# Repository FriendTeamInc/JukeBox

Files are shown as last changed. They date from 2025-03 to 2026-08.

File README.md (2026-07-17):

<p align="center">JukeBox!</p>
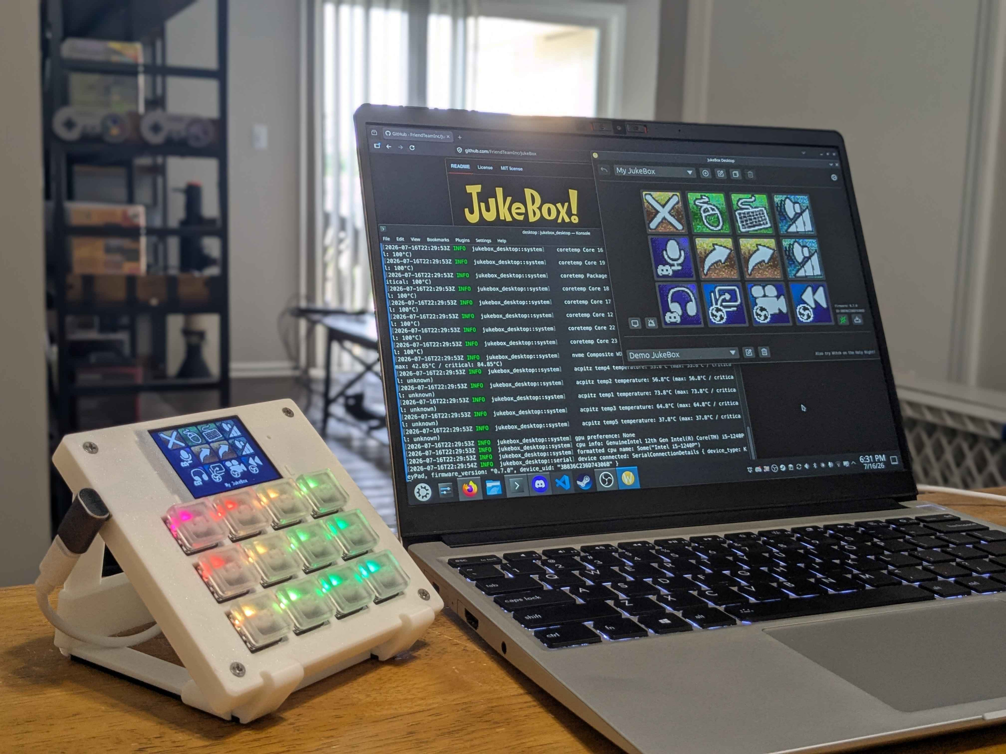
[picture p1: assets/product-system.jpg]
A JukeBox unit sitting idle on a desk with a computer.

<p align="center">An affordable, adorable, powerful hotkey device to run macros, play funny sounds, managing your audio settings, change paint brush settings, configure items in OBS, and so much more!</p>

# Disclaimer
While this project is public, it is not ready for any sort of prime time. Any releases prior to 1.0 are considered beta.

## Docs
TODO

## Desktop Software
Made with Rust and egui for Windows and Linux, curates the user experience with the JukeBox.

### Building
It's as simple as running `cargo build --release`.

### Discord support
Discord, currently, will not provide support to new projects using their RPC protocol. Because of this, JukeBox Desktop will not support Discord out of the box, despite having functionality for it built in. To use the Discord functionality in JukeBox Desktop, you must do the following:
1. Go to https://discord.com/developers/applications/ and log in with your account.
2. Create a new application and name it JukeBoxDesktop.
3. Go to the OAuth2 settings tab.
4. Copy the client ID and client secret down to a safe location.
5. Set the redirect to `https://localhost:61961`. Save your changes.
6. Go to the App Testers settings tab.
7. Add your Discord account as a tester. An email will be sent to your account email, go to your inbox and accept the invite.
8. Build with the following command: `DISCORD_CLIENT_ID="<PUT_CLIENT_ID_HERE>" DISCORD_CLIENT_SECRET="<PUT_CLIENT_SECRET_HERE>" cargo run --features "discord" --release`.

## Device Firmware
TODO

### Building
1. (Linux only) Add yourself to the dialout group with the following: `sudo usermod -a -G dialout $USER`. Install the [RPi Pico udev rules](https://github.com/raspberrypi/picotool/blob/master/udev/99-picotool.rules). Add the following rules:
```
SUBSYSTEM=="usb", \
    ATTRS{idVendor}=="2e8a", \
    ATTRS{idProduct}=="000c", \
    TAG+="uaccess" \
    MODE="660", \  
    GROUP="plugdev"
```

2. Install the appropriate target toolchain: `rustup target add thumbv6m-none-eabi`.
3. Install [cmake](https://cmake.org/download/) for tool compilation.
4. (Linux only) Install libudev-dev: `sudo apt install libudev-dev`.
5. Install tools: `cargo install flip-link`.
5. Install tools: `cargo install --locked probe-rs-tools`. This is for installing firmware over Pico probe.
6. Run `cargo run -F "keypad"` to install the keypad firmware to the connected device. You can use pedalpad or knobpad too.

## Case
Made with OpenSCAD 2025.03.31 (development snapshot), protects everything inside the JukeBox. You can get the printable STLs with the `build.sh` script.

## PCB
Made with KiCad 10, the external brains of the JukeBox.

Footprints and models:
- [Cherry/Kailh Switch footprint based on this.](https://github.com/luke-schutt/Pi5Keyboard/blob/main/Pi5-pcb/Pi5Footprints.pretty/Low%20Profile%20GC%20plus%20MX.kicad_mod)

Estimated power usage is 5 volts at 0.1 amps, or 0.5 watts.

### Bill of Materials
| Ref | Part No. | Qty | Value | DNP |
|---|---|-----|---|-----|
| R1, R5, R14 | RMCF0402FT1K00 | 3 | 1k | |
| R3, R4 | RMCF0402FT27R0 | 2 | 27 | |
| R6, R7 | RMCF0402FT5K11 | 2 | 5.11k | |
| R8-11 | RMCF0402FT10K0 | 4 | 10k | |
| R12 | RMCF0402FT10K0 | 1 | 10k | |
| R13 | RMCF0402FT10R0 | 1 | 10 | |
| R15 | RMCF0402FT33R0 | 1 | 33 | |
| C1, C2 | GRM21BR61C106KE15K | 2 | 10u | |
| C3, C4 | GCM1555C1H150JA16D | 2 | 15p | |
| C5, C9, C11-18 | GRM155R71E104KE14J | 10  | 100n  | |
| C6-8, C10 | GRM155R60J475ME47D | 4 | 4.7u  | |
| L1 | AOTA-B201610S3R3-101-T | 1 | 3.3u  | |
| D1-12 | 1N4148W-SOD-123 | 12  | | |
| D13-24 | WS2812B-2020 | 12  | | |
| D25 | 150080GS75000 | 1 | | |
| J1 | USB4105-GF-A | 1 | | |
| Q1 | S8050-SOT-23 | 1 | | |
| SW1-12 | Keyboard Key Switch | 12  | |  X  |
| SW13 | PTS636SKG25SMTR LFS | 1 | | |
| U1 | AZ1117IH-3.3TRG1 | 1 | | |
| U2 | W25Q32JVSSIQ | 1 | | |
| U3 | RP2350A | 1 | | |
| U4 | TFTQ-T20ST22ZP01 | 1 | |  X  |
| U4 | FH34SRJ-22S-0.5SH(50)  | 1 | | |
| U5 | CAT24C128WI-GT3 | 1 | | |
| Y1 | ABM8-272-T3 | 1 | | |

# License
Copyright (c) 2020-2026 Logan "NotQuiteApex" Hickok-Dickson

All programming files, found in [`firmware/`](firmware/), [`software/`](software/), and [`case/`](case/), are licensed under the [MIT license](https://mit-license.org/).

All CAD files, found in [`hardware-pcb/`](hardware-pcb/), unless otherwise provided by an external source such as footprints or 3D models, are licesned under the [CC BY-NC-SA license](https://creativecommons.org/licenses/by-nc-sa/4.0/).

Both licenses can be found with the given links or as files in the root of this repostiory.

If you would like to sell a variation of the board designed by you, reach out and an alternative license can be discussed and granted.

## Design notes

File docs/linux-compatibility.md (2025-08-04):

# Linux Compatibility
You must add yourself to the `dialout` group in order for device communication to function: `sudo usermod -a -G dialout $USER`

You must also install the udev rules below for device communication to function.

## udev Rules
The following udev rules allow device communication access for all users in the dialout group, and device firmware update permissions for all users in the plugdev group. The latter is only necessary for manual updating.
```udev
SUBSYSTEM=="tty", ATTRS{idVendor}=="1209", ATTRS{idProduct}=="f209", TAG+="uaccess" MODE="0660", GROUP="dialout"
SUBSYSTEM=="tty", ATTRS{idVendor}=="1209", ATTRS{idProduct}=="f20a", TAG+="uaccess" MODE="0660", GROUP="dialout"
SUBSYSTEM=="tty", ATTRS{idVendor}=="1209", ATTRS{idProduct}=="f20b", TAG+="uaccess" MODE="0660", GROUP="dialout"
SUBSYSTEM=="tty", ATTRS{idVendor}=="1209", ATTRS{idProduct}=="f20c", TAG+="uaccess" MODE="0660", GROUP="dialout"
SUBSYSTEM=="usb", ATTRS{idVendor}=="2e8a", ATTRS{idProduct}=="0003", TAG+="uaccess" MODE="0660", GROUP="plugdev"
```

## Dependencies
Debian/Ubuntu:
`sudo apt install libgtk-3-dev libxdo-dev libayatana-appindicator3-dev`

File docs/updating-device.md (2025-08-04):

# Updating Your JukeBox Device Firmware
There are two methods for updating your JukeBox, using the desktop application and manually flashing the firmware.

## 1. Updating via the Desktop Application
1. Connect your device to your computer and open the desktop application. Your device is connected when the desktop application shows a green plug symbol.
2. Click the update button next to the green plug symbol to open the update page. Do note, that if you haven't already, you may need to configure the device to be allowed to update on [Windows with Zadig](windows-compatibility.md#updating-the-device-firmware) or [Linux with udev rules](windows-compatibility.md#updating-the-device-firmware).
3. Click the front and center update button, and allow the application to flash new firmware onto the device. You can also load a custom firmware file with the CFW button, though this is not recommended nor supported.
4. All done! Enjoy your updated device!

## 2. Manually Flashing New Firmware on Tour Device
1. Unplug the device from your computer.
2. Locate the BOOT button on your device. Hold this button down.
    - On the JukeBox KeyPad, this BOOT button is above the rightmost key next to the screen.
3. While holding the button, connect the device to your computer. The device SHOULD NOT boot or light up normally.
4. Let go of the BOOT button. A USB storage device should appear in your file explorer, named something like "RPI-RP2".
5. Download the latest firmware [here](https://github.com/FriendTeamInc/JukeBox/releases/latest). The firmware is a UF2 file.
6. Drag and drop the firmware into the "RPI-RP2" storage device and wait for the transfer to complete. When finished, your JukeBox device will reboot with the latest firmware installed.
7. All done! Enjoy your updated device!

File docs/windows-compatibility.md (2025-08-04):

# Windows Compatibility
Windows users should not need any extra software or drivers to use the JukeBox device or desktop application. However, updating the firmware using the desktop application does require the installation of a Zadig driver.

## Updating the Device Firmware
If you have not done so before, when updating the device firmware you will need to install a driver for the device to be updated by the desktop application. To do so, follow these steps:

1. Connect your device to your computer, open the application, and open the firmware update page for your device when the device connects.
2. Click the update button. The device will reboot with a blank screen, and the update will fail with an error. Do NOT unplug the device yet.
3. Download and open [Zadig](https://zadig.akeo.ie/). In the dropdown, find and select the device named "RP2 Boot". For the driver, select WinUSB and click the install button. You are free to close Zadig now.
4. Now, reconnect your device to your computer, it should appear to function as it did before.
5. Navigate back to the firmware update page for your device, and attempt to update the device. It should reboot successfully with the latest firmware installed.

From now on you should be free to install new firmware using just the desktop application!

## Problematic Software
The following programs are known to cause issue with serial ports, which JukeBox uses to communicate between the device and the application over USB. When these applications run, it may be impossible for the JukeBox device to connect to the desktop application.

- [UltiMaker Cura](https://ultimaker.com/software/ultimaker-cura/)
- [NZXT CAM](https://nzxt.com/pages/cam)

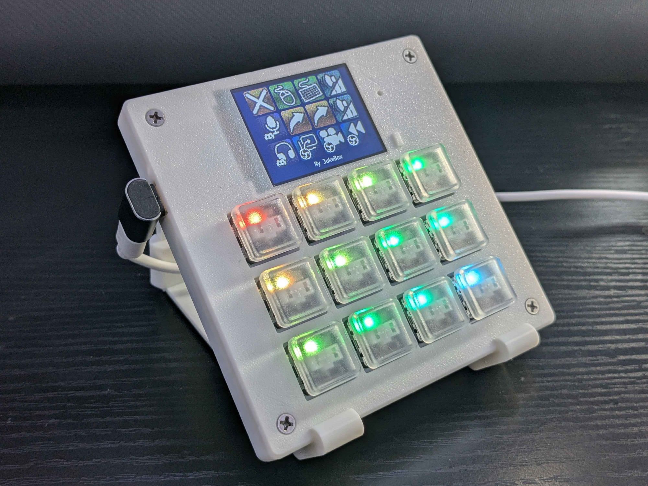
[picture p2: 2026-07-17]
assets/product-solo.jpg

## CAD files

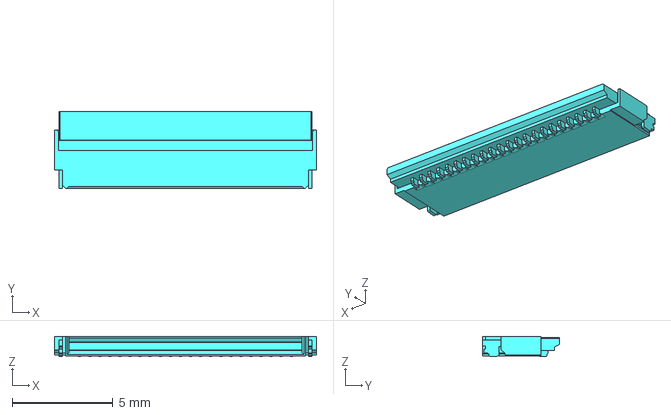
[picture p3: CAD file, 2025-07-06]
pcb/footprints/FH34SRJ-22S-0.5SH_50_.step
13.0 x 3.80 x 1.00 mm

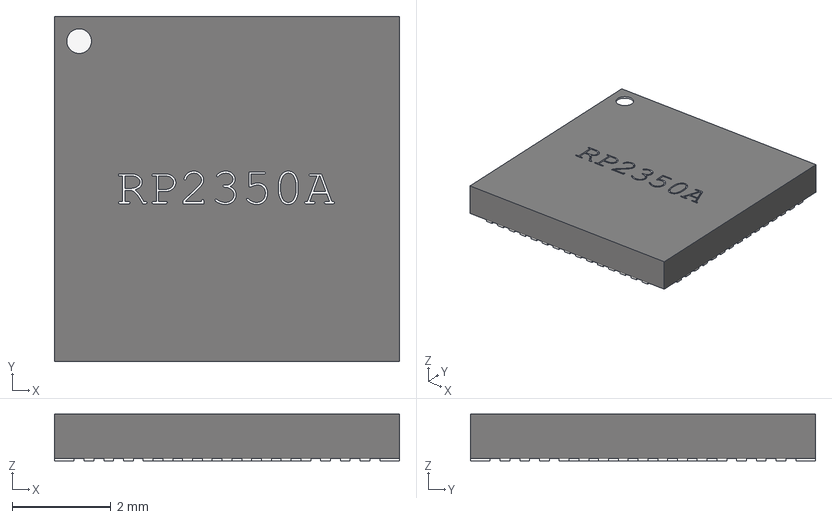
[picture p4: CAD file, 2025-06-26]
pcb/footprints/RP2350_QFN60.step
7.00 x 7.00 x 0.95 mm

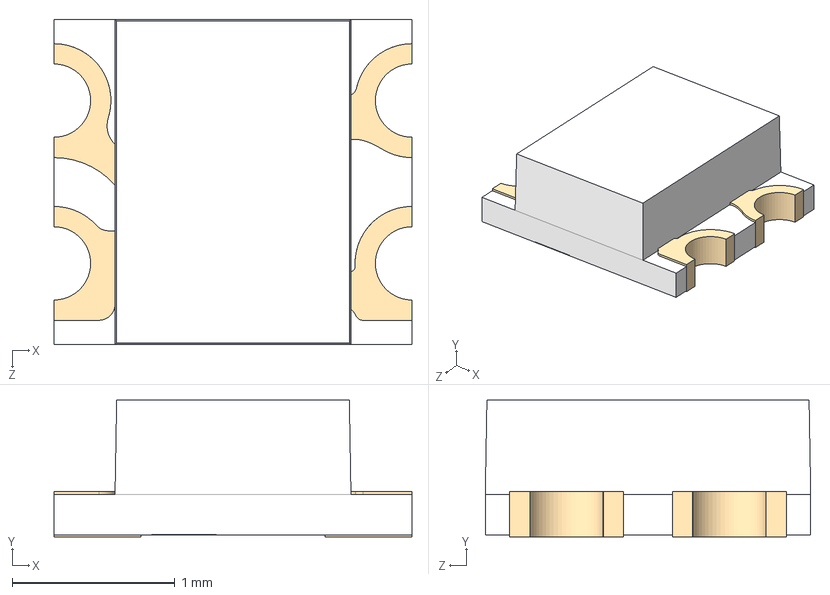
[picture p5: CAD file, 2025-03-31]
pcb/footprints/WS2812-2020.STEP
2.20 x 0.84 x 2.00 mm

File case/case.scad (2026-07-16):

// JukeBox Case

/* [General settings] */
// Case size (width & height)
cS = 108;
// Case corner radius (rounded corners)
cR = 3;
// Case mounting hardware offset
cmO = 7.5;
// Case mounting hardware bolt size
cmB = 3.5;
// Case mounting hardware nut size (center to corner)
cmN = 3.3;
// Face count on rounded objects
$fn=32;
// Case connector hole size
ioHS = 10;
// Case connector hole offset
ioHO = cS-cmO-17.5;
// Case connector hole buffer
ioHB = 0.125;
// Debug Port
dbgPort = false;
// Reset button width
rbW = 2.5;
// Reset button height
rbH = 5;

/* [Case top settings] */
// Case top height
ctH = 8;
// Case top wall size
ctW = 2.5;
// Case top mounting plate size
ctM = 9;
// Case top mounting plate height
ctMH = 3.4;

/* [Case bottom settings] */
// Case bottom lip height
clH = 3;
// Case bottom lip chamfer size
clC = 1;
// Case bottom lip size
clS = 3;
// Case bottom PCB corner radius (rounded corners)
cpR = 3;
// Case bottom PCB height
cpH = 2.6;
// Case bottom PCB wall size
cpW = 3;
// Case bottom PCB mounting plate size
cpM = 9;
// Case bottom rubber feet spot offset
cpF = 20;
// Case bottom rubber feet spot diameter
cpFD = 10;
// Case bottom rubber feet spot depth
cpFH = 2;

/* [Logo settings] */
// Logo size scale
logoS = 0.035;
// Logo position (X)
logoX = 49;
// Logo position (Y)
logoY = 83;

/* [Keyboard settings] */
// Keyboard key size
kbS = 17;
// Keyboard key matrix position (X)
kbX = cS/2;
// Keyboard key matrix position (Y)
kbY = 39;
// Keyboard key matrix offset (X)
kbOX = 30;
// Keyboard key matrix offset (Y)
kbOY = 20;
// Keyboard key matrix width
kbW = 4;
// Keyboard key matrix height
kbH = 3;
// Keyboard key matrix spacing width
kbSW = 20;
// Keyboard key matrix spacing height
kbSH = 20;

/* [Case leg settings] */
// Leg width
clipW = 13;
// Leg rounding radius
clipR = 4;
// Leg Brace width
braceW = 20;

/* [Case screen settings] */
// Screen Cutout width
csScrCW = 57.5;
// Screen Cutout height
csScrCH = 36.5;
// Screen Window width
csScrWW = 42.5;
// Screen Window height
csScrWH = 32.5;

module rect4(x1, y1, x2, y2, h) {
    translate([x1, y1, h]) children();
    translate([x2, y1, h]) children();
    translate([x1, y2, h]) children();
    translate([x2, y2, h]) children();
}
module square4(s1, s2, h) {
    rect4(s1, s1, s2, s2, h) children();
}
// https://www.youtube.com/watch?v=gKOkJWiTgAY
module roundedsquare(xdim, ydim, zdim, rdim){
    hull() {
        rect4(rdim, rdim, xdim-rdim, ydim-rdim, 0) cylinder(h=zdim, r=rdim);
    }
}
module chamferedsquare(xdim, ydim, zdim, r1dim, r2dim){
    bigrdim = max(r1dim, r2dim);
    hull() {
        rect4(bigrdim, bigrdim, xdim-bigrdim, ydim-bigrdim, 0) cylinder(h=zdim, r1=r1dim, r2=r2dim);
    }
}

module speaker_icon() {
    scale([5/6, 5/6, 1]) {
        difference() {
            cylinder(r=7, h=1, center=true);
            cylinder(r=6, h=1, center=true);
        }
        cube([1, 13, 1], center=true);
        translate([ 4, 0, 0]) cube([1, 10, 1], center=true);
        translate([-4, 0, 0]) cube([1, 10, 1], center=true);
        translate([0, -2.25, 0]) cube([12, 1, 1], center=true);
        translate([0,  2.25, 0]) cube([12, 1, 1], center=true);
    }
}

SOX = cS / 2 - (csScrCW + ctW * 2) / 2; // screen origin x
SOY = cS - 18 - ctW - csScrCH / 2-2.75; // screen origin y

module case_reset_button() {
    b = 3;
    c = 0.25;
    cube([rbW+b, rbH+b, 0.4]);
    translate([b/2+c/2, b/2+c/2, 0.4]) cube([rbW-c, rbH-c, 2.4]);
}

module case_top() {
    difference() {
        union() {
            difference() {
                union() {
                    // Top shell body
                    translate([0, 0, ctH]) chamferedsquare(cS, cS, 1, 3, 2);
                    roundedsquare(cS, cS, ctH, cR);
                }
                union() {
                    // USB-C hole
                    translate([-1, ioHO-ioHS, -1]) cube([ctW+2, ioHS, ctH+1]);
                    // Interior
                    translate([ctW, ctW, -1]) roundedsquare(cS-ctW*2, cS-ctW*2, ctH+1, cR);

                    // identify led cutout
                    translate([cS-25.5, cS-17.5, ctH]) cylinder(h=1, d=2);
                    // reset button cutout
                    translate([cS-28.75, cS-36.75, ctH]) cube([rbW, rbH, 1]);
                }
            }

            // LED light pipe
            difference() {
                translate([cS-25.5, cS-17.5, ctH-2.8]) cylinder(h=2.8, d=4);
                translate([cS-25.5, cS-17.5, ctH-2.8]) cylinder(h=2.8, d=2);
            }

            h = ctH-ctMH;
            ctMW = ctM+ctW;

            // Mounting plates
            square4(0, cS-ctMW, h) roundedsquare(ctMW, ctMW, ctMH, cpR);
            translate([    cmO,           0, h]) cube([cS - cmO*2, ctM+1.5, ctMH]);
            translate([    cmO,    cS-cmO-4, h]) cube([cS - cmO*2, ctM+1.5, ctMH]);
            translate([      0,           0, h]) roundedsquare(ctMW, ctMW+60, ctMH, cpR);
            translate([cS-ctMW,           0, h]) roundedsquare(ctMW, ctMW+60, ctMH, cpR);
            translate([      0,  cS-ctMW-12, h]) roundedsquare(ctMW, ctMW+12, ctMH, cpR);

            // Supports (screen)
            translate([SOX, SOY, 0]) union() {
                translate([ctW+(csScrCW+csScrWW)/2+2, ctW+(csScrCH+csScrWH)/2-.75, h]) cube([20, 3, ctMH]);
                translate([ctW-(csScrCW-csScrWW)/2-12.5, ctW+(csScrCH+csScrWH)/2-.75, h]) cube([20, 3, ctMH]);

                translate([ctW+(csScrCW-cS)/2, 1, h]) cube([cS, 1.5, ctMH]);
            }

            // Supports (keyboard)
            translate([0, 47.5, h]) cube([cS, 3, ctMH]);
            translate([0, 27.5, h]) cube([cS, 3, ctMH]);

            // alignment holders
            difference(){
                bS = 100;
                bBS = 0.25;
                translate([0, 0, h-1]) roundedsquare(cS, cS, 1, cR);
                translate([(cS-(bS+bBS))/2, (cS-(bS+bBS))/2, h-2]) cube([bS+bBS, bS+bBS, 2]);
                translate([0, cS-36.5, h-2]) cube([cS, 25, 2]);
            }
        }

        union() {
            // keyboard key holes
            kX = kbX-kbOX;
            kY = kbY-kbOY;
            ch = ctH + 1;
            for (w=[0:kbW-1]) {
                for (h=[0:kbH-1]) {
                    translate([kX + kbSW * w, kY + kbSH * h, ch]) cube([kbS, kbS, 2], center=true);
                }
            }

            // mounting hardware holes
            square4(cmO, cS - cmO, ctH - 4) {
                cylinder(d=cmB, h=5);
                translate([0, 0, 2]) cylinder(d2=6, d1=2, h=3);
            }


            // Screen cutout
            translate([SOX, SOY, 0]) union() {
                // Screen Window
                translate([ctW+(csScrCW-csScrWW)/2, ctW+(csScrCH-csScrWH)/2, ctH]) cube([csScrWW, csScrWH, 1]);
                // Inset
                translate([ctW+(csScrCW+csScrWW)/2+2-52, 2.5, 0]) cube([52, csScrCH, 8.8]);
            }
            
            // Jukebox logo
            // case_detail();

            // Debug port cutout
            if (dbgPort) {
                translate([cS-ctW, cS-17.5-4-18, 0]) cube([ctW, 18, ctH-ctMH]);
            }
        }
    }
}

module case_bottom() {
    difference() {
        union() {
            // Case floor
            chamferedsquare(cS, cS, clC, cR-clC, cR);
            translate([0, 0, clC]) roundedsquare(cS, cS, clH-clC, cR);

            // PCB table
            difference() {
                translate([    clS,     clS, clH]) roundedsquare(cS-clS*2, cS-clS*2, cpH, cpR);
                translate([clS+cpW, clS+cpW, clH]) cube([cS-clS*2-cpW*2, cS-clS*2-cpW*2, cpH]);
            }
            square4(clS, cS-clS*2-cpW*2, clH) roundedsquare(cpM, cpM, cpH, cpR);

            // USB-C pillar
            translate([0, ioHO-ioHS+ioHB, clH]) cube([1.5, ioHS-ioHB*2, 4]);
        }

        union() {
            cmO2 = cS-cmO;
            nH = 2.375;
            square4(cmO, cmO2, 0) cylinder(d=cmB, h=7);
            square4(cmO, cmO2, 0) cylinder($fn=6, r=cmN, h=nH);
            square4(cmO, cmO2, nH) cylinder($fn=6, r1=cmN, r2=cmB/2, h=1);

            // Indents for rubber feet
            square4(cpF, cS-cpF, 0) cylinder(d=cpFD, h=cpFH/2);
            square4(cpF, cS-cpF, cpFH/2) cylinder(d1=cpFD, d2=cpFD-2, h=cpFH/2);

            // cutout for through hole components
            translate([clS, ioHO-ioHS+ioHB, clH]) cube([10, ioHS-ioHB*2, cpH]);

            // Debug port cutout
            if (dbgPort) {
                translate([cS-ctW-20, cS-17.5-4-18, clH]) cube([ctW+20, 18, ctH]);
            }
        }
    }
}
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

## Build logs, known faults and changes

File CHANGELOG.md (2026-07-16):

# v0.7.0 - Asynchronous (July 15, 2026)
Note: This update is for a new hardware revision of JukeBox and will not work with older beta units. Do not use this or newer versions with older hardware.
- Upgrade microcontroller to RP2350 (from RP2040).
- Switch firmware to use Embassy for better task management on device.
- Upgrade screen (same ST7789 interface, larger bus size from 1 bit to 8 bits).
- Upgrade case to support new hardware.
- Fix screen and RGB editor in desktop app.
- Fix temperature reporting for certain CPUs.
- Improve connection to OBS and Discord on startup.
- Dramatically improve screen graphics performance.
- Dynamically dim and brighten screen on computer sleep and wakeup.
- Add dynamic icons for certain actions to display status, such as being muted on Discord.
- Add profile duplicate button.
- Profiles now switch when creating a new profile or duplicating a profile.
- Re-enable system tray support for Windows.
- Update dependencies for desktop app and firmware.

# v0.6.1 - But Not Serialized (August 5, 2025)
- Fix firmware having too big of a serial buffer, causing a crash on startup.
- Fix versioning issue with firmware and software.
- Fix action icon size in software.

# v0.6.0 - Defaultized (August 5, 2025)
- Added EEPROM support to firmware. A default, app-disconnected profile can now be set. Support in GUI will be added at a later date.
- Added "sleep mode" for when host computer goes to sleep (suspends USB), turning off the screen and RGB.
- Increase max number of colors for Wave and Breathe RGB patterns from 4 to 16.
- Update Screen profile max size to be 256 bytes.
- Update RGB Profile max size to be 64 bytes.
- Unify USB HID Events (keyboard and mouse) in code and protocol.
- Update links to documentation for Windows and Linux setup intro messages.
- Add a drop down select for RGB Static Per Key pattern.
- Change default profile in software for keypad to the F13-24 keys.
- Fix identify function having messed up offsets for the blinking LED.
- Allow profile name to be hidden on screen.
- Update dependencies for desktop app and firmware.

# v0.5.0 - Tut Trials (June 27, 2025)
- Add a welcome message on very first startup with some important info for the user.
- Remove donate "link".
- Add "Breathe" RGB pattern configuration.
- Add "Wave" RGB pattern configuration.
- Fix RGB previews, specifically the rounded corners.
- Enable NVIDIA GPU monitoring support. AMD support will be added later once cross compiling is sorted.
- Update dependencies for desktop app and firmware.

# v0.4.6 - I'm Blue (June 26, 2025)
- Update default theme for device when not connected to application. This now includes an indicator of USB connection status (red if not connecting, green if connected with host), the device's UID, and its firmware version. It's also blue now.
- Fix "N/A" temperature not displaying correctly on device.

# v0.4.5 - Clock Forever (June 22, 2025)
- Fix keyboard key requests being way too frequent.
- Only send RGB and Screen packets to keypad devices, futureproofing.

# v0.4.4 - Initiliazing Fixes (June 22, 2025)
- Fix potential device nickname collisions on first connection.
- Fix device not receiving default configuration on first connection.

# v0.4.3 - Patch TODOs (June 21, 2025)
- Switch Profile action will now better switch its target profile when the original target profile is deleted or renamed.
- Disable CPU temperature read out on Windows (since Windows and sysinfo do not have methods to read temperature currently).
- Add info statement to list device firmware and UID on connection.
- Fix application remembering device firmware of a disconnected device.
- Take last 4 characters of UID for name instead of first 4 due to collisions.
- Fix panics and stuck loops when packet length read fails.
- Fix stuck loop when serial disconnects with data in its buffer.
- The above fixes do not solve the random disconnects that serial experiences, and will need to be investigated further later. For some reason, either the application drops random bytes, or the firmware consumes random bytes.

# v0.4.2 - IADs Fix (June 15, 2025)
- Fix device not functioning on Windows due to misconfigured USB descriptors.

# v0.4.1 - Feelin' Hot (June 14, 2025)
- Add preliminary CPU temperature reading support. This may only work on AMD-based CPU's, and has been only tested on Linux.

# v0.4.0 - Mouse Controls, Not for Mice (June 14, 2025)
- Add mouse event action in app and firmware.
- Fix device not appearing correctly as composite device.
- Fix device not requesting enough power.
- Fix device max packet size to be larger for performance.
- Update some firmware dependencies.

# v0.3.1 - Update Fixes (June 13, 2025)
- Fix inability to leave other screens after a failed update occurred.

# v0.3.0 - Icon and Save Update (June 13, 2025)
- Images of arbitrary size can be used as icons now.
- Device connection status is now more prominent.
- Added popup warning for if your config file failed to load.
- Added explicit save button on configuration screens.
- Further increase timeout of serial to be at most 250 milliseconds.

# v0.2.5 - More Stability (June 12, 2025)
- Fix USB mass storage device from appearing when the JukeBox is put into update mode from software.
- Fix firmware update confirmation button translation string.
- Adjust USB serial internal buffer sizes in firmware.
- Revert tray icon functionality for Windows while we wait for egui to add `App::tick()`.
- Force timeout of serial to be at most 100 milliseconds.
- Update firmware dependencies.

# v0.2.4 - Firmware Update Stability (June 11, 2025)
- Update internal libraries. This specifically addresses an issue where the firmware update page may fail when no drivers are available on Windows.
- Added a message to the firmware update error page to reconnect the device physically or manually update the firmware.

# v0.2.3 - Iconic Async (June 11, 2025)
- Fix icon device upload in async thread.

# v0.2.2 - Debugging Causes Problems (June 9, 2025)
- Add pop up for any errors from the update process.
- Allow console window on Windows, for any panics to be traced. This will be removed later.
- Disable blocking in firmware debug output, which causes firmware to eventually freeze.

# v0.2.1 - Albrecht Entrati (June 8, 2025)
- Major refactor internally for actions. Old config files will be discarded!
- Add lots of debug prints for the update process.
- Fix config directory missing for app lock purposes.
- Begin push for Discord integration available by default. Unfinished.
- Changed delete profile and forget device to be single click instead of double click.
- The save and exit pop up will now only show when a change has actually been made.
- Drop some old dependencies from the desktop app.

# v0.2.0 - Debugging Days (June 8, 2025)
- Changed default brightness for RGB from 255 to 100.
- Added log file for testers to send in.
- Prevent new instances of the desktop application from launching.

# v0.1.3 - Removing Some Unfinished Work (June 3, 2025)
- Fix crash when GPU name is too long.
- Rename Profile Name Color to Text Color in screen configuration.
- Finish brightness in screen configuration.
- Disabled Soundboard functionality, since it is currently unfinished.
- Disabled Wave RGB pattern, since it is currently unfinished.
- Vertically expanded the window, since on certain platforms the window is cut off at the bottom.

# v0.1.2 - Allow Updating Firmware (June 1, 2025)
- Desktop application can now download and apply new firmware.

# v0.1.1 - Minor Update Notif Fix (June 1, 2025)
- Change the Update Notification in the desktop application to show the current and new version.
- Update desktop app dependencies.
- Add changelog.

# v0.1.0 - Beta Begins (June 1, 2025)
Initial release.

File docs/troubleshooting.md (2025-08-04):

# General Troubleshooting
When you first plug in your JukeBox device, before it connects to the desktop application, it will show you several important elements.

First, a box on the bottom left to indicate USB connectivity. This box will be red if the device cannot exchange information with the host computer, which can happen if your USB cable or port malfunctions. Try using another port, another orientation, or another cable. The box will be green if the device and host computer are communicating.

Second, a unique identifier (UID) will appear at the bottom middle of the screen. This string of letters and numbers uniquely identifies this JukeBox, and is determined by the flash storage chip used on the device. This UID will also appear in your desktop application.

Third, a firmware version number in the bottom right. It's good practice to always make sure your device is up-to-date. If your device can connect to the desktop application, you can [update your device using the desktop application](flashing-firmware.md#1-updating-via-the-desktop-application). If for whatever reason the device can be detected by the host computer, but not the desktop application, you may need to [manually flash the firmware](flashing-firmware.md#2-manually-flashing-new-firmware-on-tour-device).

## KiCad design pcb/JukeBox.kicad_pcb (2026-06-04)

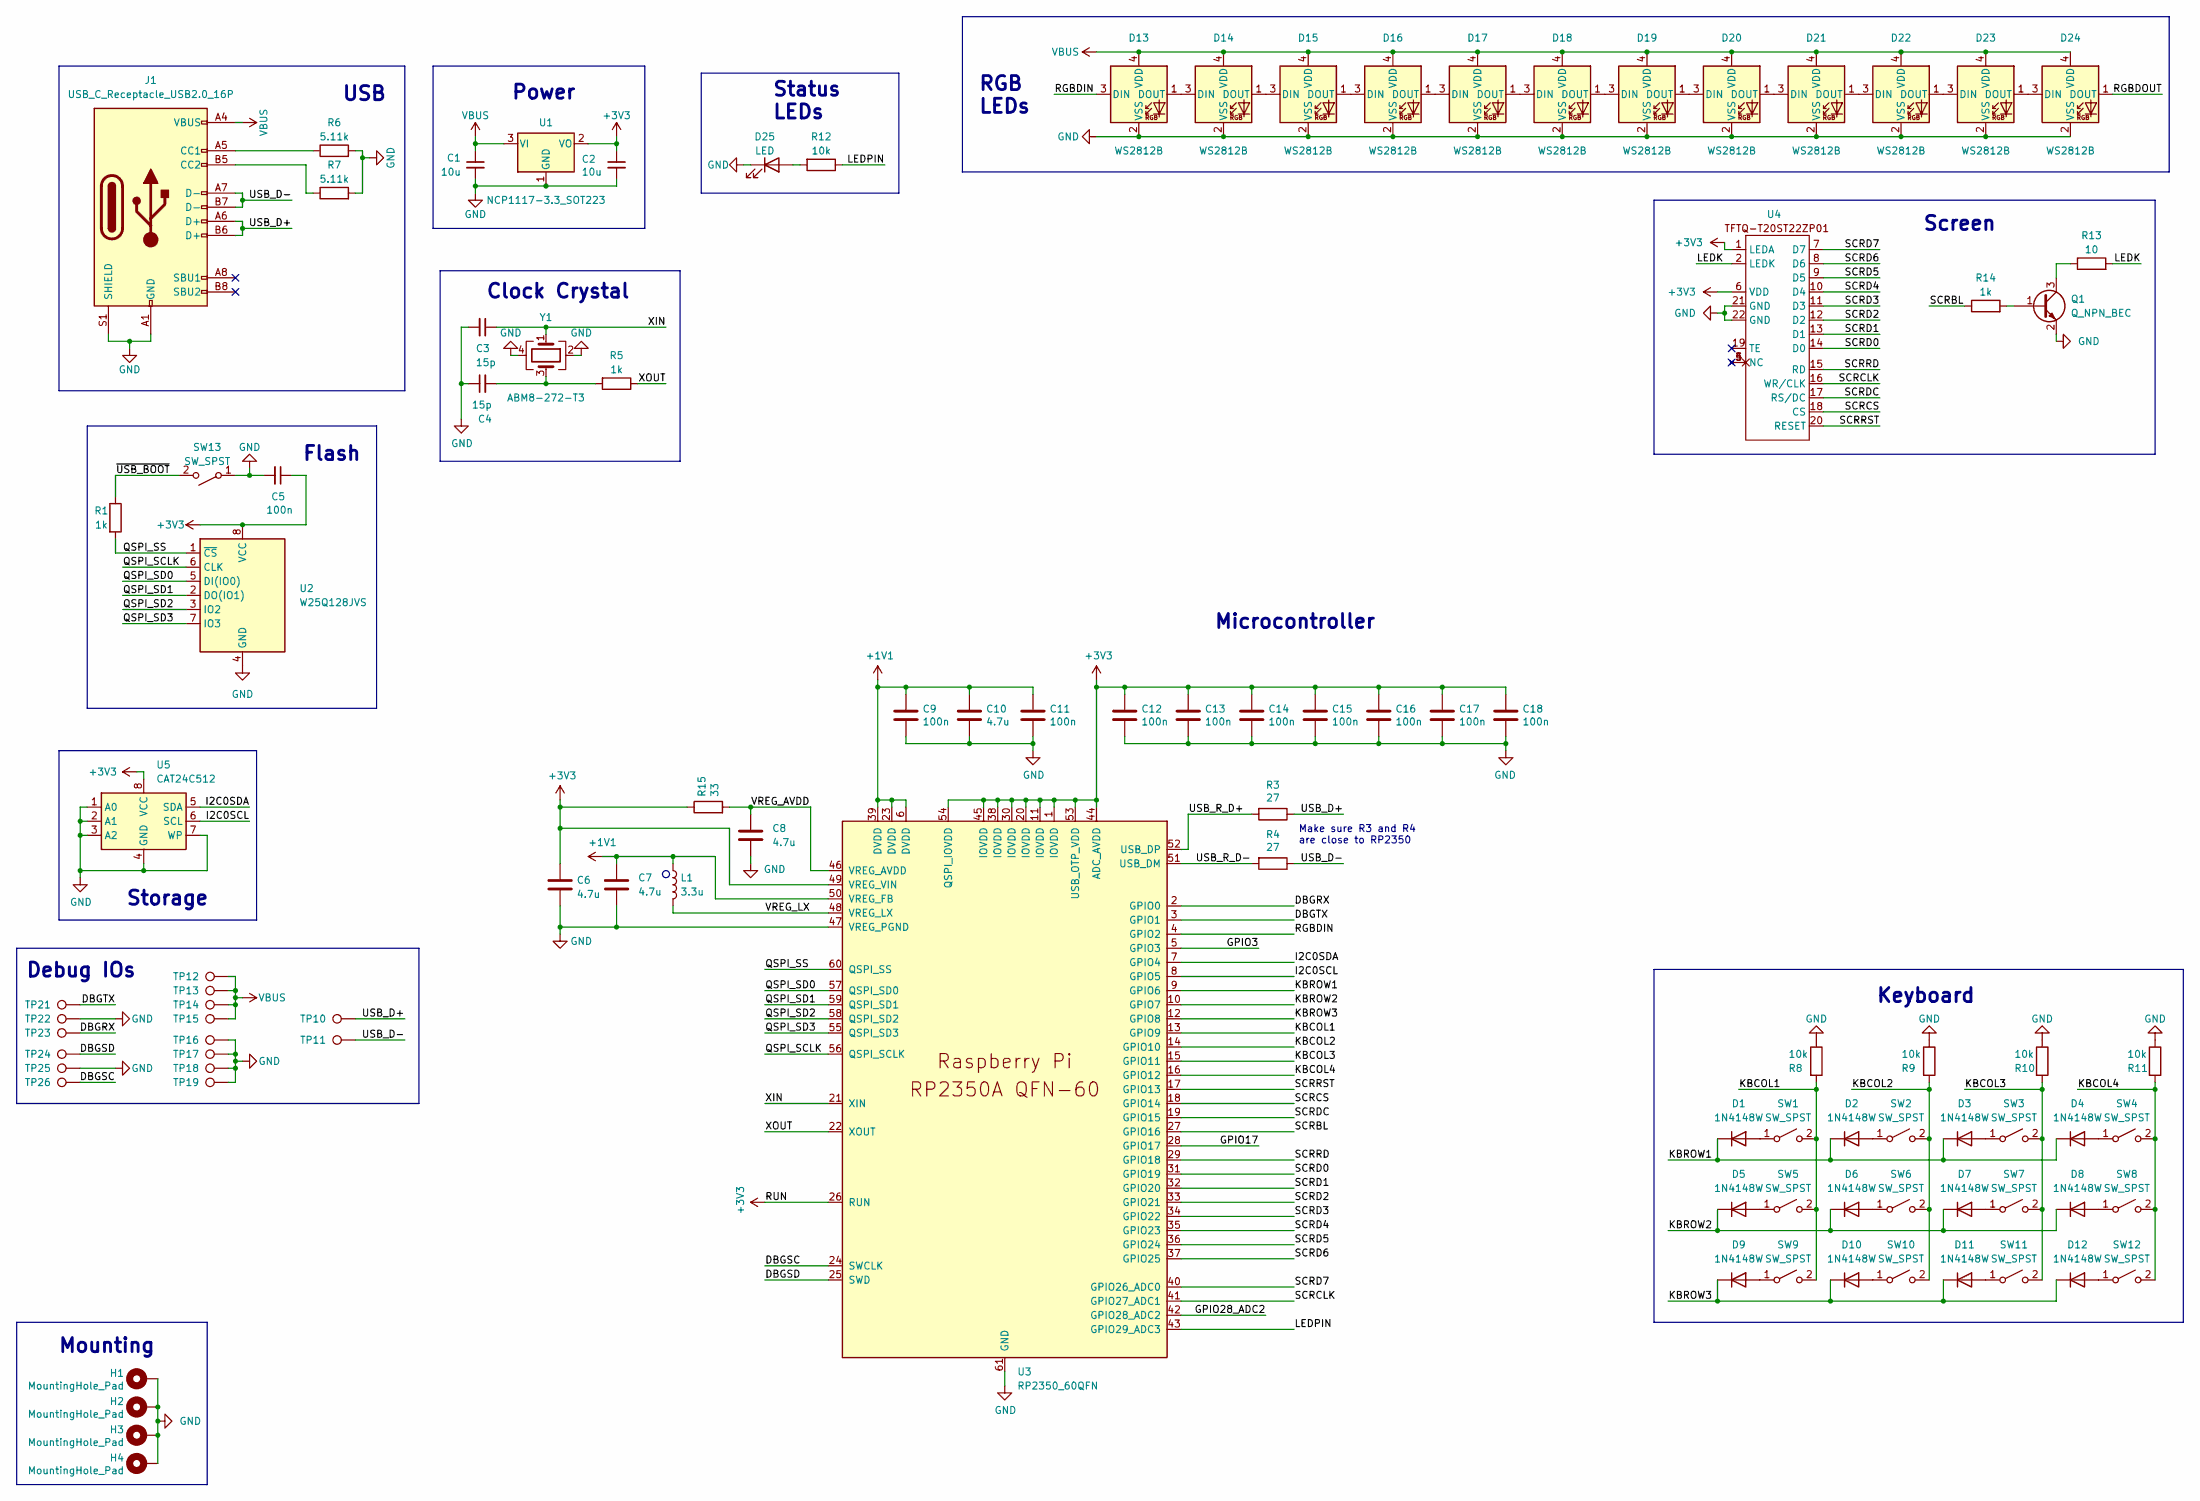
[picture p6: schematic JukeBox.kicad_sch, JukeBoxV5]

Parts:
C1, C2: 10u; C_0805_2012Metric
C3, C4: 15p; C_0402_1005Metric
C5, C9, C11, C12, C13, C14, C15, C16, C17, C18: 100n; C_0402_1005Metric
C6, C7, C8, C10: 4.7u; C_0402_1005Metric
D1, D2, D3, D4, D5, D6, D7, D8, D9, D10, D11, D12: 1N4148W; D_SOD-123
D13, D14, D15, D16, D17, D18, D19, D20, D21, D22, D23, D24: WS2812B; LED_WS2812B-2020_PLCC4_2.0x2.0mm
D25: LED; D_0805_2012Metric_Pad1.15x1.40mm_HandSolder
H1, H2, H3, H4: MountingHole_Pad; MountingHole_3.2mm_M3_Pad_Via
J1: USB_C_Receptacle_USB2.0_16P; USB_C_Receptacle_GCT_USB4105-xx-A_16P_TopMnt_Horizontal
L1: 3.3u; L_pol_2016
Q1: Q_NPN_BEC; SOT-23
R1, R5, R14: 1k; R_0402_1005Metric
R3, R4: 27; R_0402_1005Metric
R6, R7: 5.11k; R_0402_1005Metric
R8, R9, R10, R11, R12: 10k; R_0402_1005Metric
R13: 10; R_0402_1005Metric
R15: 33; R_0402_1005Metric
SW1, SW2, SW3, SW4, SW5, SW6, SW7, SW8, SW9, SW10, SW11, SW12: SW_SPST; ALLKEY
SW13: SW_SPST; SW_SPST_CK_RS282G05A3
TP10, TP11, TP12, TP13, TP14, TP15, TP16, TP17, TP18, TP19, TP21, TP22, TP23, TP24, TP25, TP26: TestPoint; TestPoint_Pad_D1.5mm
U1: NCP1117-3.3_SOT223; SOT-223-3_TabPin2
U2: W25Q128JVS; SOIC-8_5.23x5.23mm_P1.27mm
U3: RP2350_60QFN; RP2350-QFN-60-1EP_7x7_P0.4mm_EP3.4x3.4mm_ThermalVias
U4: TFTQ-T20ST22ZP01
U5: CAT24C512; SOIC-8_3.9x4.9mm_P1.27mm
Y1: ABM8-272-T3; Crystal_SMD_Abracon_ABM8G-4Pin_3.2x2.5mm

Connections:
+1V1: C7.1, C9.1, C10.1, C11.1, L1.1, U3.6 (DVDD), U3.23 (DVDD), U3.39 (DVDD), U3.50 (VREG_FB)
+3V3: C2.1, C5.1, C6.1, C12.1, C13.1, C14.1, C15.1, C16.1, C17.1, C18.1, R15.1, U1.2 (VO), U2.8 (VCC), U3.1 (IOVDD), U3.11 (IOVDD), U3.20 (IOVDD), U3.26 (RUN), U3.30 (IOVDD), U3.38 (IOVDD), U3.44 (ADC_AVDD), U3.45 (IOVDD), U3.49 (VREG_VIN), U3.53 (USB_OTP_VDD), U3.54 (QSPI_IOVDD), U4.1 (LEDA), U4.6 (VDD), U5.8 (VCC)
/DBGRX: TP23.1, U3.2 (GPIO0)
/DBGSC: TP26.1, U3.24 (SWCLK)
/DBGSD: TP24.1, U3.25 (SWD)
/DBGTX: TP21.1, U3.3 (GPIO1)
/GPIO3: U3.5 (GPIO3)
/GPIO17: U3.28 (GPIO17)
/GPIO28_ADC2: U3.42 (GPIO28_ADC2)
/I2C0SCL: U3.8 (GPIO5), U5.6 (SCL)
/I2C0SDA: U3.7 (GPIO4), U5.5 (SDA)
/KBCOL1: R8.2, SW1.2 (B), SW5.2 (B), SW9.2 (B), U3.13 (GPIO9)
/KBCOL2: R9.2, SW2.2 (B), SW6.2 (B), SW10.2 (B), U3.14 (GPIO10)
/KBCOL3: R10.2, SW3.2 (B), SW7.2 (B), SW11.2 (B), U3.15 (GPIO11)
/KBCOL4: R11.2, SW4.2 (B), SW8.2 (B), SW12.2 (B), U3.16 (GPIO12)
/KBROW1: D1.2 (K), D2.2 (K), D3.2 (K), D4.2 (K), U3.9 (GPIO6)
/KBROW2: D5.2 (K), D6.2 (K), D7.2 (K), D8.2 (K), U3.10 (GPIO7)
/KBROW3: D9.2 (K), D10.2 (K), D11.2 (K), D12.2 (K), U3.12 (GPIO8)
/LEDK: R13.2, U4.2 (LEDK)
/LEDPIN: R12.1, U3.43 (GPIO29_ADC3)
/QSPI_SCLK: U2.6 (CLK), U3.56 (QSPI_SCLK)
/QSPI_SD0: U2.5 (DI(IO0)), U3.57 (QSPI_SD0)
/QSPI_SD1: U2.2 (DO(IO1)), U3.59 (QSPI_SD1)
/QSPI_SD2: U2.3 (IO2), U3.58 (QSPI_SD2)
/QSPI_SD3: U2.7 (IO3), U3.55 (QSPI_SD3)
/QSPI_SS: R1.2, U2.1 (~CS), U3.60 (QSPI_SS)
/RGBDIN: D13.3 (DIN), U3.4 (GPIO2)
/RGBDOUT: D24.1 (DOUT)
/SCRBL: R14.1, U3.27 (GPIO16)
/SCRCLK: U3.41 (GPIO27_ADC1), U4.16 (WR/CLK)
/SCRCS: U3.18 (GPIO14), U4.18 (CS)
/SCRD0: U3.31 (GPIO19), U4.14 (D0)
/SCRD1: U3.32 (GPIO20), U4.13 (D1)
/SCRD2: U3.33 (GPIO21), U4.12 (D2)
/SCRD3: U3.34 (GPIO22), U4.11 (D3)
/SCRD4: U3.35 (GPIO23), U4.10 (D4)
/SCRD5: U3.36 (GPIO24), U4.9 (D5)
/SCRD6: U3.37 (GPIO25), U4.8 (D6)
/SCRD7: U3.40 (GPIO26_ADC0), U4.7 (D7)
/SCRDC: U3.19 (GPIO15), U4.17 (RS/DC)
/SCRRD: U3.29 (GPIO18), U4.15 (RD)
/SCRRST: U3.17 (GPIO13), U4.20 (RESET)
/USB_D+: J1.A6 (D+), J1.B6 (D+), R3.1, TP10.1
/USB_D-: J1.A7 (D-), J1.B7 (D-), R4.1, TP11.1
/USB_R_D+: R3.2, U3.52 (USB_DP)
/USB_R_D-: R4.2, U3.51 (USB_DM)
/VREG_AVDD: C8.1, R15.2, U3.46 (VREG_AVDD)
/VREG_LX: L1.2, U3.48 (VREG_LX)
/XIN: C3.1, U3.21 (XIN), Y1.1
/XOUT: R5.1, U3.22 (XOUT)
/~USB_BOOT: R1.1, SW13.2 (B)
GND: C1.2, C2.2, C3.2, C4.1, C5.2, C6.2, C7.2, C8.2, C9.2, C10.2, C11.2, C12.2, C13.2, C14.2, C15.2, C16.2, C17.2, C18.2, D13.2 (VSS), D14.2 (VSS), D15.2 (VSS), D16.2 (VSS), D17.2 (VSS), D18.2 (VSS), D19.2 (VSS), D20.2 (VSS), D21.2 (VSS), D22.2 (VSS), D23.2 (VSS), D24.2 (VSS), D25.1 (K), H1.1, H2.1, H3.1, H4.1, J1.A1 (GND), J1.A12 (GND), J1.B1 (GND), J1.B12 (GND), J1.S1 (SHIELD), Q1.2 (E), R6.2, R7.2, R8.1, R9.1, R10.1, R11.1, SW13.1 (A), TP16.1, TP17.1, TP18.1, TP19.1, TP22.1, TP25.1, U1.1 (GND), U2.4 (GND), U3.47 (VREG_PGND), U3.61 (GND), U4.21 (GND), U4.22 (GND), U5.1 (A0), U5.2 (A1), U5.3 (A2), U5.4 (GND), U5.7 (WP), Y1.2, Y1.4
unnamed: C4.2, R5.2, Y1.3
unnamed: D1.1 (A), SW1.1 (A)
unnamed: D2.1 (A), SW2.1 (A)
unnamed: D3.1 (A), SW3.1 (A)
unnamed: D4.1 (A), SW4.1 (A)
unnamed: D5.1 (A), SW5.1 (A)
unnamed: D6.1 (A), SW6.1 (A)
unnamed: D7.1 (A), SW7.1 (A)
unnamed: D8.1 (A), SW8.1 (A)
unnamed: D9.1 (A), SW9.1 (A)
unnamed: D10.1 (A), SW10.1 (A)
unnamed: D11.1 (A), SW11.1 (A)
unnamed: D12.1 (A), SW12.1 (A)
unnamed: D13.1 (DOUT), D14.3 (DIN)
unnamed: D14.1 (DOUT), D15.3 (DIN)
unnamed: D15.1 (DOUT), D16.3 (DIN)
unnamed: D16.1 (DOUT), D17.3 (DIN)
unnamed: D17.1 (DOUT), D18.3 (DIN)
unnamed: D18.1 (DOUT), D19.3 (DIN)
unnamed: D19.1 (DOUT), D20.3 (DIN)
unnamed: D20.1 (DOUT), D21.3 (DIN)
unnamed: D21.1 (DOUT), D22.3 (DIN)
unnamed: D22.1 (DOUT), D23.3 (DIN)
unnamed: D23.1 (DOUT), D24.3 (DIN)
unnamed: D25.2 (A), R12.2
unnamed: J1.A5 (CC1), R6.1
unnamed: J1.B5 (CC2), R7.1
unnamed: Q1.1 (B), R14.2
unnamed: Q1.3 (C), R13.1
VBUS: C1.1, D13.4 (VDD), D14.4 (VDD), D15.4 (VDD), D16.4 (VDD), D17.4 (VDD), D18.4 (VDD), D19.4 (VDD), D20.4 (VDD), D21.4 (VDD), D22.4 (VDD), D23.4 (VDD), D24.4 (VDD), J1.A4 (VBUS), J1.A9 (VBUS), J1.B4 (VBUS), J1.B9 (VBUS), TP12.1, TP13.1, TP14.1, TP15.1, U1.3 (VI)

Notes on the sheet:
Flash
Mounting
Make sure R3 and R4 are close to RP2350
Debug IOs
Storage
Keyboard
USB
RGB LEDs
Screen
Power
Clock Crystal
Microcontroller
Status LEDs

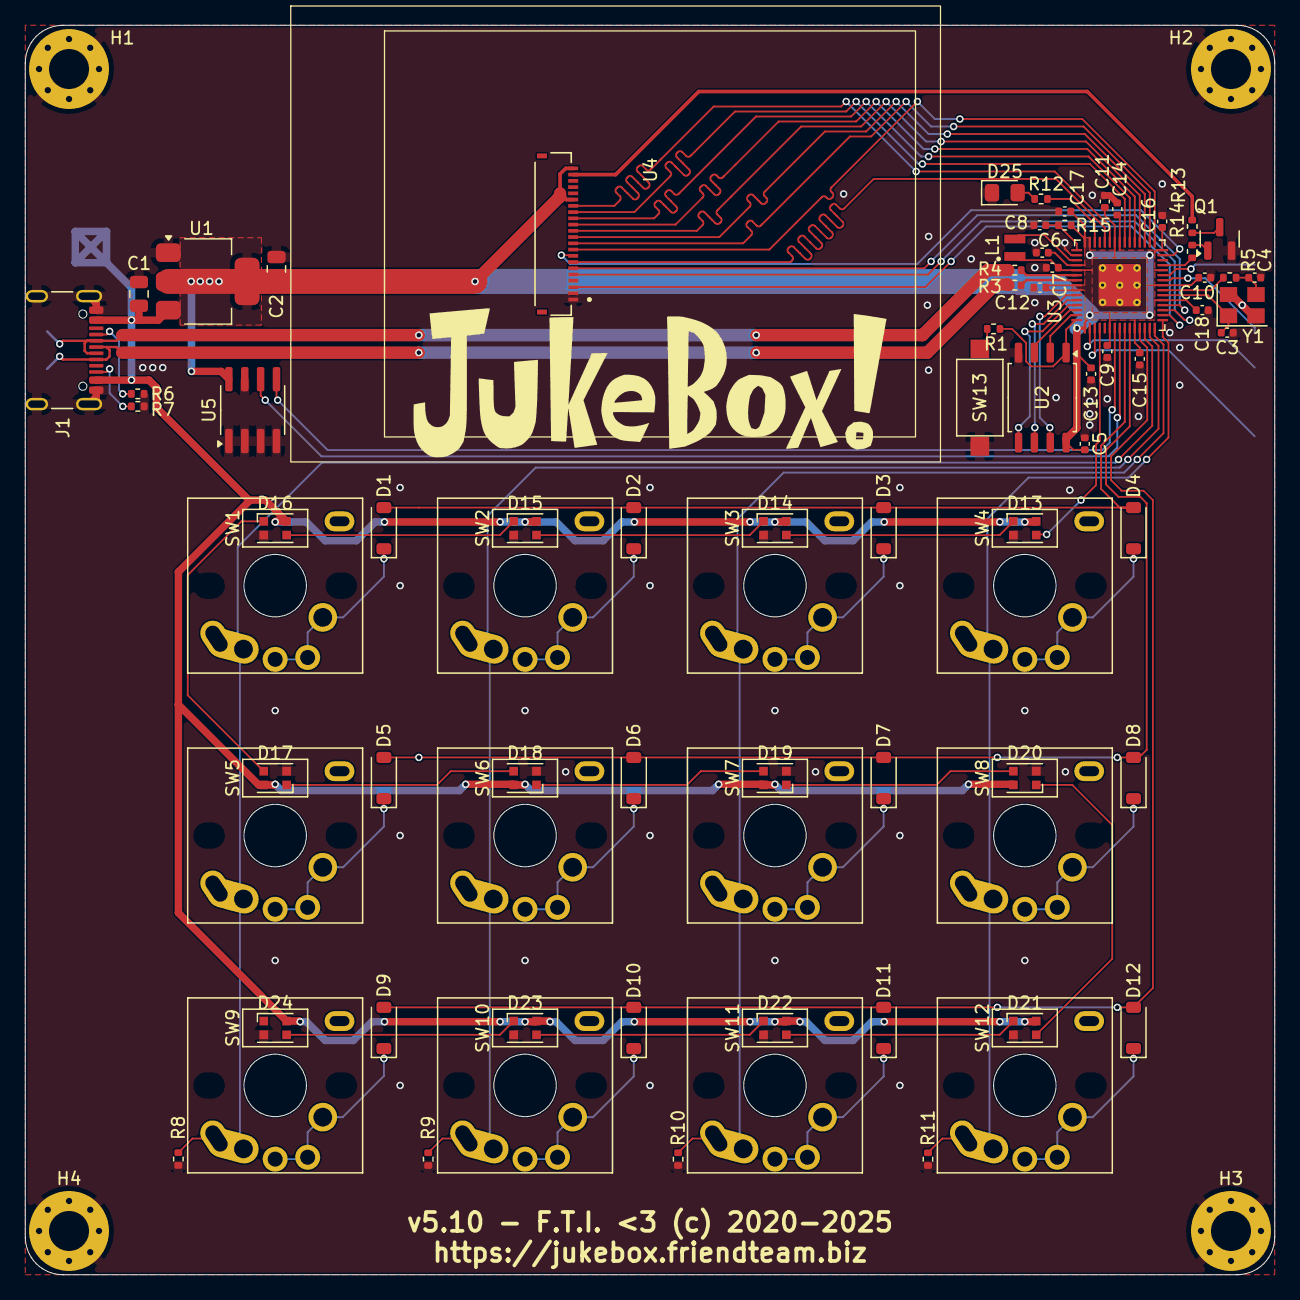
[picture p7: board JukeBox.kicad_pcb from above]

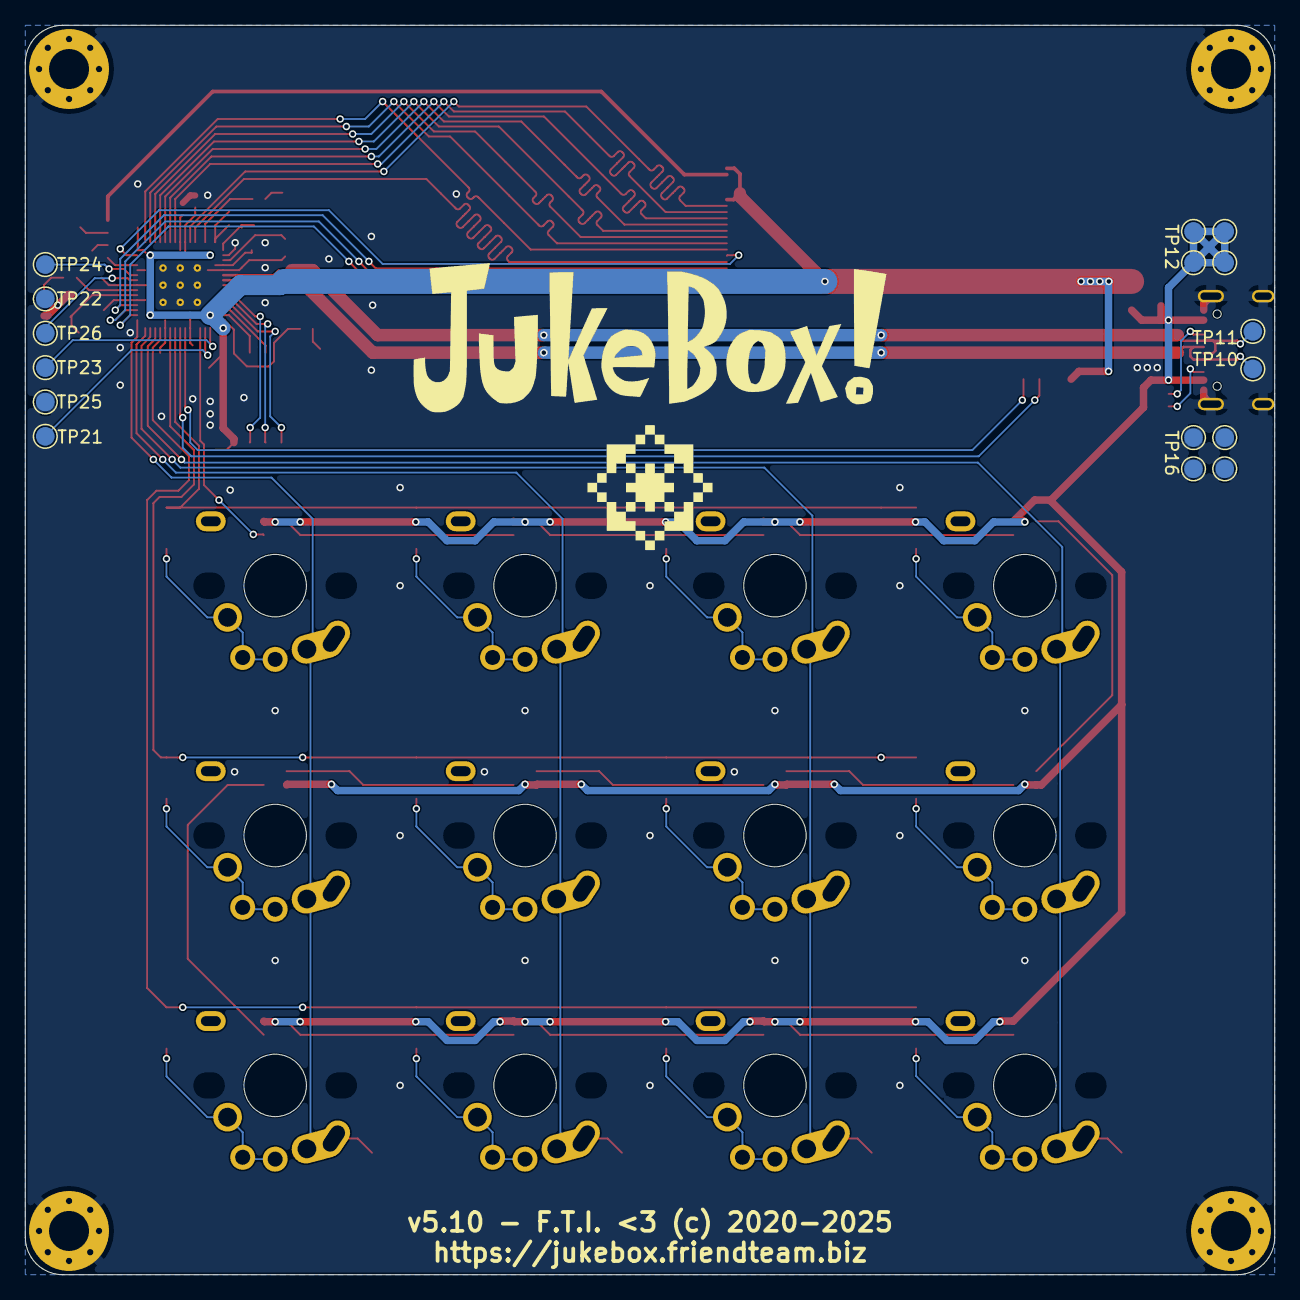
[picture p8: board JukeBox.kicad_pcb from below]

Board: 2 copper layers, 100.0 x 100.0 mm, 101 parts (17 on the bottom side), 78 nets.

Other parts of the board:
G1, G1#2: LOGO; JukeBox

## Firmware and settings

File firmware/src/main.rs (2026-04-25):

//! JukeBox Async Firmware
//!
//! Built with Embassy

#![no_std]
#![no_main]

mod eeprom;
mod identify;
mod keypad;
mod rgb;
mod screen;
mod serial;
mod uid;
mod usb;
mod util;

use defmt::*;

use {defmt_rtt as _, panic_probe as _};

use embassy_executor::Executor;
use embassy_rp::{
    clocks::{ClockConfig, CoreVoltage, clk_sys_freq, core_voltage},
    config::Config,
    gpio,
    multicore::{Stack, spawn_core1},
    pwm,
};
use static_cell::StaticCell;

static mut CORE1_STACK: Stack<40_000> = Stack::new();
static EXECUTOR0: StaticCell<Executor> = StaticCell::new();
static EXECUTOR1: StaticCell<Executor> = StaticCell::new();

#[cortex_m_rt::entry]
fn main() -> ! {
    // Hello, world!

    // Overclock to 300MHz
    let clock_config = {
        let mut c = ClockConfig::system_freq(250_000_000).unwrap();
        c.core_voltage = CoreVoltage::V1_20;
        Config::new(c)
    };

    // Initialize peripherals
    let p = embassy_rp::init(clock_config);

    // Set up the UID and print some system info
    uid::setup_uid();
    info!("Hey, all! JukeBox here!");
    info!("Version: {}", env!("CARGO_PKG_VERSION"));
    info!("UID: {}", uid::get_uid());
    info!("Core Clock: {} MHz", clk_sys_freq() / 1_000_000);
    info!("Core Voltage: {} V", core_voltage().unwrap());

    // Break out pins for peripherals
    // // EEPROM
    // let eeprom_sda = Output::new(p.PIN_4, Level::Low);
    // let eeprom_scl = Output::new(p.PIN_5, Level::Low);
    // LED
    let led_pin = pwm::Pwm::new_output_b(p.PWM_SLICE6, p.PIN_29, pwm::Config::default());
    // Keypad
    let kp_rows = [
        gpio::Output::new(p.PIN_6, gpio::Level::Low),
        gpio::Output::new(p.PIN_7, gpio::Level::Low),
        gpio::Output::new(p.PIN_8, gpio::Level::Low),
    ];
    let kp_cols = [
        gpio::Input::new(p.PIN_9, gpio::Pull::None),
        gpio::Input::new(p.PIN_10, gpio::Pull::None),
        gpio::Input::new(p.PIN_11, gpio::Pull::None),
        gpio::Input::new(p.PIN_12, gpio::Pull::None),
    ];
    // RGB
    let rgb_pio = p.PIO0;
    let rgb_dma = p.DMA_CH0;
    let rgb_pin = p.PIN_2;
    // Screen
    let scr_pio = p.PIO1;
    let scr_dma = p.DMA_CH1;
    let fb_dma = p.DMA_CH2;
    let scr_data = (
        p.PIN_19, p.PIN_20, p.PIN_21, p.PIN_22, p.PIN_23, p.PIN_24, p.PIN_25, p.PIN_26,
    );
    let scr_clk = p.PIN_27;
    let scr_rd = gpio::Output::new(p.PIN_18, gpio::Level::High);
    let scr_cs = gpio::Output::new(p.PIN_14, gpio::Level::High);
    let scr_dc = gpio::Output::new(p.PIN_15, gpio::Level::Low);
    let scr_bl = pwm::Pwm::new_output_a(p.PWM_SLICE0, p.PIN_16, pwm::Config::default());
    let scr_rst = gpio::Output::new(p.PIN_13, gpio::Level::High);

    // Run all peripherals on core1
    // Peripheral tasks recieve data from the serial task
    // Only the keyboard task sends data to the USB task, for USB HID
    spawn_core1(
        p.CORE1,
        unsafe { &mut *core::ptr::addr_of_mut!(CORE1_STACK) },
        move || {
            let executor1 = EXECUTOR1.init(Executor::new());
            executor1.run(|spawner| {
                unwrap!(spawner.spawn(identify::identify_task(led_pin)));
                unwrap!(spawner.spawn(rgb::rgb_task(rgb_pio, rgb_dma, rgb_pin)));
                unwrap!(spawner.spawn(screen::screen_task(
                    scr_pio, scr_dma, scr_data, scr_clk, scr_rd, scr_cs, scr_dc, scr_bl, scr_rst,
                    fb_dma
                )));
                unwrap!(spawner.spawn(keypad::keypad_task(kp_rows, kp_cols)));
            });
        },
    );

    // Run all USB and serial processing on core0
    // USB task sends serial data to serial task, and pulls key info from keyboard peripheral for USB HID
    // Serial task processes all commands and sends relevant data to the other core for use
    let executor0 = EXECUTOR0.init(Executor::new());
    executor0.run(|spawner| {
        unwrap!(usb::usb_task(p.USB, &spawner));
        unwrap!(spawner.spawn(serial::serial_task()));
    });
}

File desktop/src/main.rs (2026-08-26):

// A desktop application for interfacing with a JukeBox over serial.

// #![cfg_attr(not(debug_assertions), windows_subsystem = "windows")] // disables console spawning for release build

use anyhow::bail;
use fd_lock::RwLock;
use reqwest::Client;
use std::fs::OpenOptions;

use crate::config::JukeBoxConfig;

#[macro_use]
extern crate rust_i18n;
i18n!("locales", fallback = "en");

mod actions;
mod config;
mod firmware_update;
mod gui;
mod input;
mod serial;
mod software_update;
mod splash;
mod system;

// static http client for various api calls
// we also set the user agent to something specific to this software
// (some api's reject requests with no user agent)
static REQWEST_CLIENT: std::sync::OnceLock<reqwest::Client> = std::sync::OnceLock::new();
pub fn get_reqwest_client() -> &'static reqwest::Client {
    REQWEST_CLIENT.get_or_init(|| {
        Client::builder()
            .user_agent(format!("JukeBoxDesktop/{}", env!("CARGO_PKG_VERSION")))
            .build()
            .unwrap()
    })
}

fn main() -> anyhow::Result<()> {
    // setup config folder
    JukeBoxConfig::get_dir();

    // we only allow one instance of jukebox to run so lock the app file
    let mut f = RwLock::new(
        OpenOptions::new()
            .read(true)
            .write(true)
            .create(true)
            .open(JukeBoxConfig::get_app_lock())
            .unwrap(),
    );
    let fl = f.try_write();
    if let Err(_) = fl {
        // TODO: send signal to other app to reopen window
        bail!("failed to acquire exclusive lock for application. aborting.");
    };

    // set up logging folder
    {
        use flexi_logger::{Duplicate, FileSpec, LogSpecification, Logger};

        Logger::try_with_env_or_str("info")
            .unwrap_or_else(|_| Logger::with(LogSpecification::info()))
            .log_to_file(
                FileSpec::default()
                    .directory(JukeBoxConfig::get_logs_dir())
                    .basename("jukebox_desktop"),
            )
            .duplicate_to_stderr(Duplicate::All)
            .start()
            .ok();
    }

    // For OBS websocket TLS support, currently unused.
    // rustls::crypto::aws_lc_rs::default_provider()
    //     .install_default()
    //     .expect("failed to install rustls crypto provider");

    // GUI launches all the necessary threads when started
    gui::gui::basic_gui();

    drop(fl);

    Ok(())
}

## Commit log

2025-03-31 Initial commit.
    [JukeBox.kicad_pcb, JukeBox.kicad_sch, SM04B-SRSS-TB(LF)(SN).STEP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]
2025-04-01 switch to async reqwest api
2025-04-02 fix broken hardware buttons with old actions
2025-04-03 use device nickname instead of uid
2025-04-07 properly transpose the screen such that the top left corner of the device is the origin
2025-04-07 dma over pio, a bunch of screen work
2025-04-07 some fixes, add more function for gui to update device screen
    [screen.rs]
2025-04-08 fix screen setting, add screen setting to firmware
    [screen.rs, util.rs]
2025-04-08 add sysinfo and start thread for it
2025-04-09 push system stats over the wire
2025-04-12 add software update thread for checking for updates on github
2025-04-19 update screen cutout and add cutout for flash button on top case
    [case.scad]
2025-04-21 final adjustments for case for beta test
    [case.scad]
2025-06-04 fix some crashes and disable some unfinished stuff, and expand the window vertically
    [screen.rs]
2025-06-08 prevent more than one app from running, add debug log file to config directory
    [main.rs, screen.rs]
2025-06-08 switch from dyn trait to enum for sanity
2025-06-08 major internal refactor, begin push for standard discord integration, change delete profile and device to single click and fix directory issue
    [main.rs]
2025-06-10 add error popup for updating firmware, allow console on windows, and fix firmware eventually freezing
    [main.rs]
2025-06-10 fix usb lines on pcb
    oops.
    [JukeBox.kicad_pcb]
2025-06-12 fix icon device upload in async context
2025-06-12 update dependencies for desktop for picoboot fix, add message to firmware update error screen
    [main.rs]
2025-06-13 disable usb storage for firmware mode, fix firmware update error screen ok button, revert tray functionality for windows, force serial timeout to be 100 milliseconds
    [main.rs]
2025-06-13 add explicit save button to all config screens, increase serial timeout to 250 ms
2025-06-15 add mouse event, bunch of usb fixes, update some dependencies
    [main.rs, util.rs]
2025-06-15 add preliminary cpu temperature support
2025-06-15 fix iad configuration for windows and enable control buffer 256 for usb-device crate
    [main.rs]
2025-06-16 improve switch profile targetting deleted/modified profiles and disable cpu temp on windows
2025-06-19 new case legs (with brace)
    [case.scad]
2025-06-21 add log for device uid and firmware version on connect, fix application remembering device firmware when disconnected
2025-06-21 clear serial buffer when resetting connection, fix default naming on device connection
    these are temporary fixes for a problem that needs further investigation
    [main.rs]
2025-06-22 fix nickname collisions on new device added, fix device not receiving the initial configuration on first connection
    [main.rs]
2025-06-22 fix keyboard key requests being way too fast, only send RGB and Screen packets to keypad devices as futureproofing
2025-06-26 update case for new pcb layout
    [case.scad]
2025-06-26 massive pcb rework for rp2350
    [JukeBox.kicad_pcb, JukeBox.kicad_sch, RP2350_QFN60.step]
2025-06-27 add new screen footprint and route traces. update bom
    [FFC2B35-22-G_REVA2.step, JukeBox.kicad_pcb, JukeBox.kicad_sch]
2025-06-27 update default theme for the device, fix "N/A" temperature displaying on device
    [main.rs, screen.rs, util.rs]
2025-06-27 fix some todo's, switch serialconnectiondetails to just use device type
2025-06-28 fix rgb preview corners
    [screen.rs]
2025-06-29 update case to fit new screen and pcb better
    [case.scad]
2025-06-29 more pcb updates
    [JukeBox.kicad_pcb]
2025-06-29 finalize screen placement on pcb, add spacer to scad, add bumps to legs for binding to the case better
    [JukeBox.kicad_pcb, case.scad]
2025-06-30 big print plate of parts for case, fix leg brace calculation
    [case.scad]
2025-07-06 add cutout for rubber on case legs
    [case.scad]
2025-07-06 update to new part on pcb for screen
    [FH34SRJ-22S-0.5SH_50_.step, JukeBox.kicad_pcb]
2025-07-06 update bom
2025-07-12 finalize power rails for new screen
    [JukeBox.kicad_pcb]
2025-07-13 reorder screen pins (will make programming later easier)
    [JukeBox.kicad_pcb, JukeBox.kicad_sch]
2025-07-13 add bootsel button instead of pad
    [JukeBox.kicad_pcb, JukeBox.kicad_sch]
2025-07-14 finalize pinout and routing for screen, add models for missing components
    [FFC2B35-22-G_REVA2.step, JukeBox.kicad_pcb, JukeBox.kicad_sch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]
2025-07-14 update footprint, do drc checking, ready for order
    [JukeBox.kicad_pcb]
2025-07-25 switch to bincode for encoding/decoding data, lots of work on eeprom
2025-07-25 switch to unified input events, add some shorthand for serial responses
    [util.rs]
2025-07-25 let mutex functions return stuff, lots of formatting changes, update identify function to not seem as buggy
    [main.rs, screen.rs, util.rs]
2025-07-30 fix designator for clock crystal
    [JukeBox.kicad_pcb, JukeBox.kicad_sch]
2025-08-03 fix suspend packets not appearing by accepting keyboard packets
    [main.rs]
2025-08-05 start switch to embassy
2025-08-05 fix cicd, add uid, start on usb
    [main.rs, usb.rs]
2025-08-05 build out usb comms, indicate suspended status on led, fix cicd builds properly
    [main.rs, usb.rs]
2025-08-06 fix firmware crash, fix icon size in software, fix version numberings
    [main.rs, screen.rs, util.rs]
2025-08-09 update case for debug port cutout
    [case.scad]
2025-08-10 fix poll rate for identify and keypad
    [identify.rs]
2025-08-11 finish screen driver, add some test code for it
2025-08-12 more screen work. draw function is locking things up, fix that later
    [main.rs, screen.rs, util.rs]
2025-08-13 fix floating read clock on screen, which causes the screen to hang on startup
    [JukeBox.kicad_pcb, JukeBox.kicad_sch]
2025-08-14 update pcb to add missing pin for screen
    ugh
    [JukeBox.kicad_pcb, JukeBox.kicad_sch]
2025-08-14 DNP updates for BOM
    [JukeBox.kicad_pcb, JukeBox.kicad_sch]
2025-09-04 fix screen driver not working, add scr_rd pin for newer boards to control
    [main.rs, screen.rs]
2025-10-11 fix frame drawing breaking from overly large rectangles, update info on frame drawing timings
    [main.rs, screen.rs]
2025-10-11 fix missing pre-tick draw on startup
    [main.rs, screen.rs]
2026-01-06 updated screen configuration for device
2026-01-09 switch off of bincode since its no longer supported
    [screen.rs]
2026-01-24 fix temperature reporting for my CPU
    [main.rs]
2026-04-24 fix firmware not building (rearrange firmware irq binds)
    [screen.rs, usb.rs, util.rs]
2026-04-25 attempt to optimize screen pin configs
2026-04-25 remove pixel transposing and configure display to read memory in correct orientation
    [screen.rs]
2026-04-26 minor adjustments to the case top
    [case.scad]
2026-04-26 remove soundboard, add led pillar to case, and start certain services on app startup
    [case.scad]
2026-05-04 update chagelog, add feature switch for log mode, minor adjustment to discord authentication at launch
2026-05-30 add duplicate profile button, switch profiles whenever the new or dupe button is pressed, and update dependencies
2026-05-31 update kicad project to kicad 10.0
    [JukeBox.kicad_pcb, JukeBox.kicad_sch]
2026-05-31 fix dnp for key resistors
    [JukeBox.kicad_sch]
2026-06-04 shorten pcb to reduce cost
    [JukeBox.kicad_pcb]
2026-06-19 add some better alignment for the pcb in the case, and add a button for bootsel
    [case.scad]
2026-07-01 switch to voice settings test to find an error rq
2026-07-01 switch back to regular voice settings branch
2026-07-01 don't block on discord initialization stuff, add reconnect button, remove reconnection attempts from discord actions
2026-07-16 update dependencies
    cannot update egui yet until amPerl/egui-phosphor#41 merges
    [case.scad]
2026-08-17 switch to new logger, reduce some cross module type usage
2026-08-19 switch to uuid for profiles
2026-08-20 fix action thread, only a few bits remain

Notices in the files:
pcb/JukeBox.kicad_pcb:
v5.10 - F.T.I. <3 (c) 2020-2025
